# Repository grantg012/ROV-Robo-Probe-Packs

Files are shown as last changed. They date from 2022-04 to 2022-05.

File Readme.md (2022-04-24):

# Readme for ROV - Robo Probe Packs

This PCB serves as a integration layer for basic ROVs (though it could be
creatively used in other applications). It is designed for modularity and
fitting multiple different configurations. Perfect for high schoolers with
a little electronics experience, but not PCB design.

Features include:
* Pins for connecting to an Arduino Uno or Mega (use double sides ones for best effect)
* 12V+ input with reverse voltage protection
* Connections to common 12V -> 5V converters (such as ...)
* Up to 6 Electronic Speed Controllers (with options for protection circuitry)
* Breakouts for servos and I2C
* Primarily through hole components for easy soldering

## See `versions` for schematic PDFs and gerber files

## Parts List
* Arduino Uno or Mega
* Anderson power pole to PCB (1377G12 or similar)

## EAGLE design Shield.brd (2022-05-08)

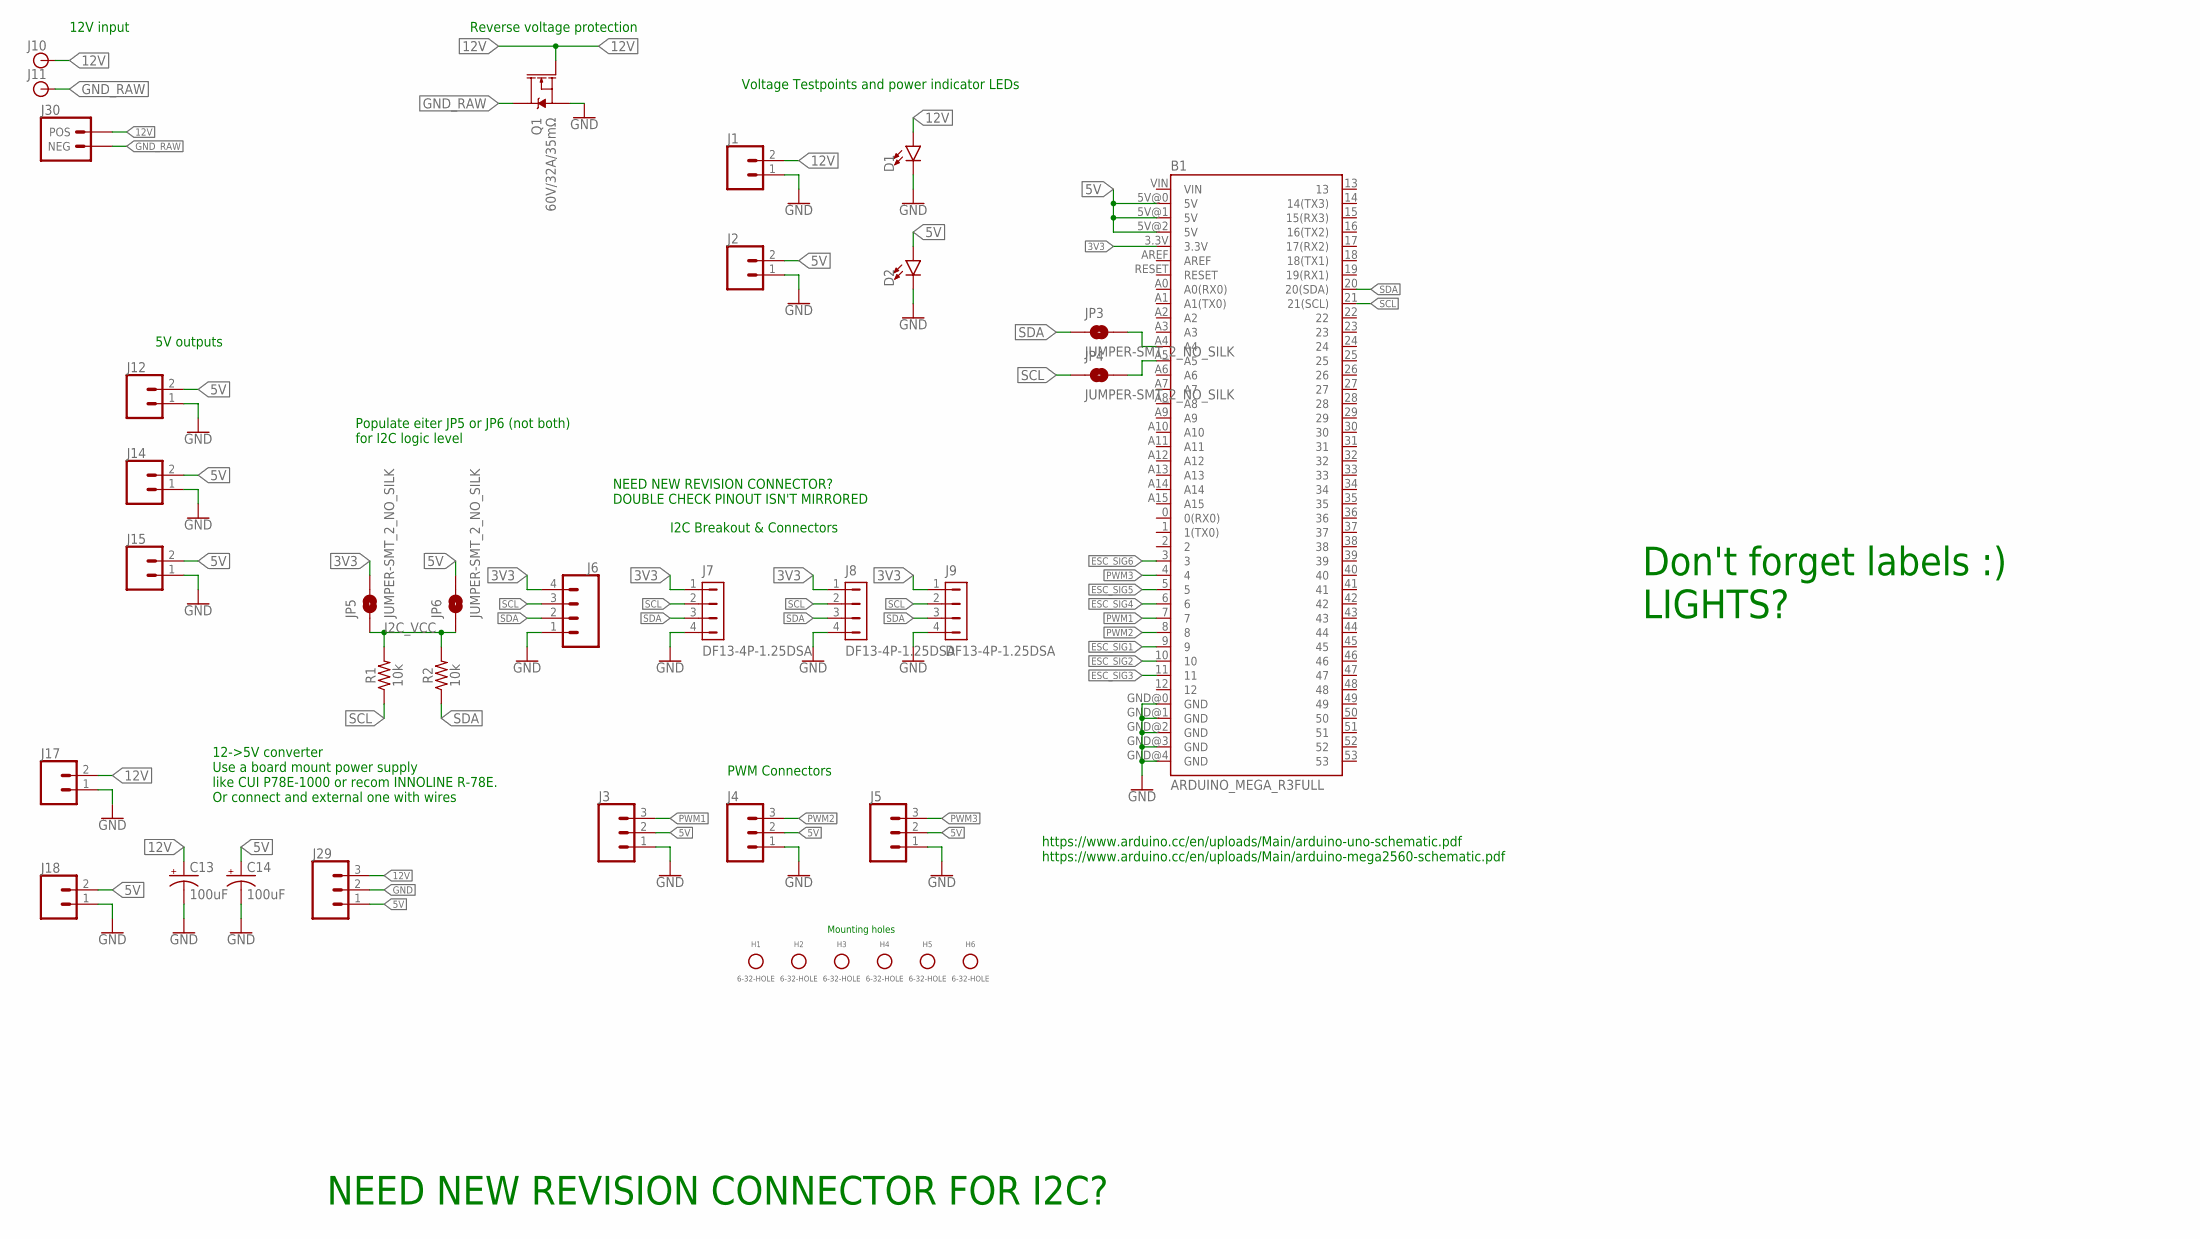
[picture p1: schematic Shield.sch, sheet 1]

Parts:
B1: ARDUINO_MEGA_R3FULL; ARDUINO_MEGA
C13, C14: 100uF; CPOL-RADIAL-2.5MM-6.5MM
D1, D2: LED3MM; LED_3MM
H1, H2, H3, H4, H5, H6: 6-32-HOLE
J1, J2, J12, J14, J15, J17, J18: CONN_02; 1X02
J3, J4, J5, J29: CONN_03; 1X03
J6: CONN_04; 1X04
J7, J8, J9: DF13-4P-1.25DSA
J10, J11: BANANA_PTH; BANANA_CONN_NO_THERM
J30: ANDERON_POWERPOLE_2
JP3, JP4, JP5, JP6: JUMPER-SMT_2_NO_SILK; SMT-JUMPER_2_NO_SILK
Q1: 60V/32A/35mΩ; TO220V
R1, R2: 10k; AXIAL-0.3

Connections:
3V3: B1.3.3V, J6.4, J7.1, J8.1, J9.1, JP5.2
5V: B1.5V@0 (5V), B1.5V@1 (5V), B1.5V@2 (5V), C14.1 (+), D2.A, J2.2, J3.2, J4.2, J5.2, J12.2, J14.2, J15.2, J18.2, J29.1, JP6.2
12V: C13.1 (+), D1.A, J1.2, J10.1, J17.2, J29.3, J30.POS, Q1.1 (G); also elsewhere on the board
A4_SDA: B1.A4, JP3.2
A5_SCL: B1.A5, JP4.2
ESC_SIG1: B1.9; also elsewhere on the board
ESC_SIG2: B1.10; also elsewhere on the board
ESC_SIG3: B1.11; also elsewhere on the board
ESC_SIG4: B1.6; also elsewhere on the board
ESC_SIG5: B1.5; also elsewhere on the board
ESC_SIG6: B1.3; also elsewhere on the board
GND: B1.GND@0 (GND), B1.GND@1 (GND), B1.GND@2 (GND), B1.GND@3 (GND), B1.GND@4 (GND), C13.2 (-), C14.2 (-), D1.K (C), D2.K (C), J1.1, J2.1, J3.1, J4.1, J5.1, J6.1, J7.4, J8.4, J9.4, J12.1, J14.1, J15.1, J17.1, J18.1, J29.2, Q1.3 (S); also elsewhere on the board
GND_RAW: J11.1, J30.NEG, Q1.2 (D)
I2C_VCC: JP5.1, JP6.1, R1.P$2 (2), R2.P$2 (2)
PWM1: B1.7, J3.3
PWM2: B1.8, J4.3
PWM3: B1.4, J5.3
SCL: B1.21 (21(SCL)), J6.3, J7.2, J8.2, J9.2, JP4.1, R1.P$1 (1)
SDA: B1.20 (20(SDA)), J6.2, J7.3, J8.3, J9.3, JP3.1, R2.P$1 (1)

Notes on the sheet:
12V input
12->5V converter Use a board mount power supply like CUI P78E-1000 or recom INNOLINE R-78E. Or connect and external one with wires
5V outputs
https://www.arduino.cc/en/uploads/Main/arduino-uno-schematic.pdf https://www.arduino.cc/en/uploads/Main/arduino-mega2560-schematic.pdf
Reverse voltage protection
Voltage Testpoints and power indicator LEDs
Don't forget labels :) LIGHTS?
I2C Breakout & Connectors
PWM Connectors
Mounting holes
Populate eiter JP5 or JP6 (not both) for I2C logic level
NEED NEW REVISION CONNECTOR? DOUBLE CHECK PINOUT ISN'T MIRRORED
NEED NEW REVISION CONNECTOR FOR I2C?

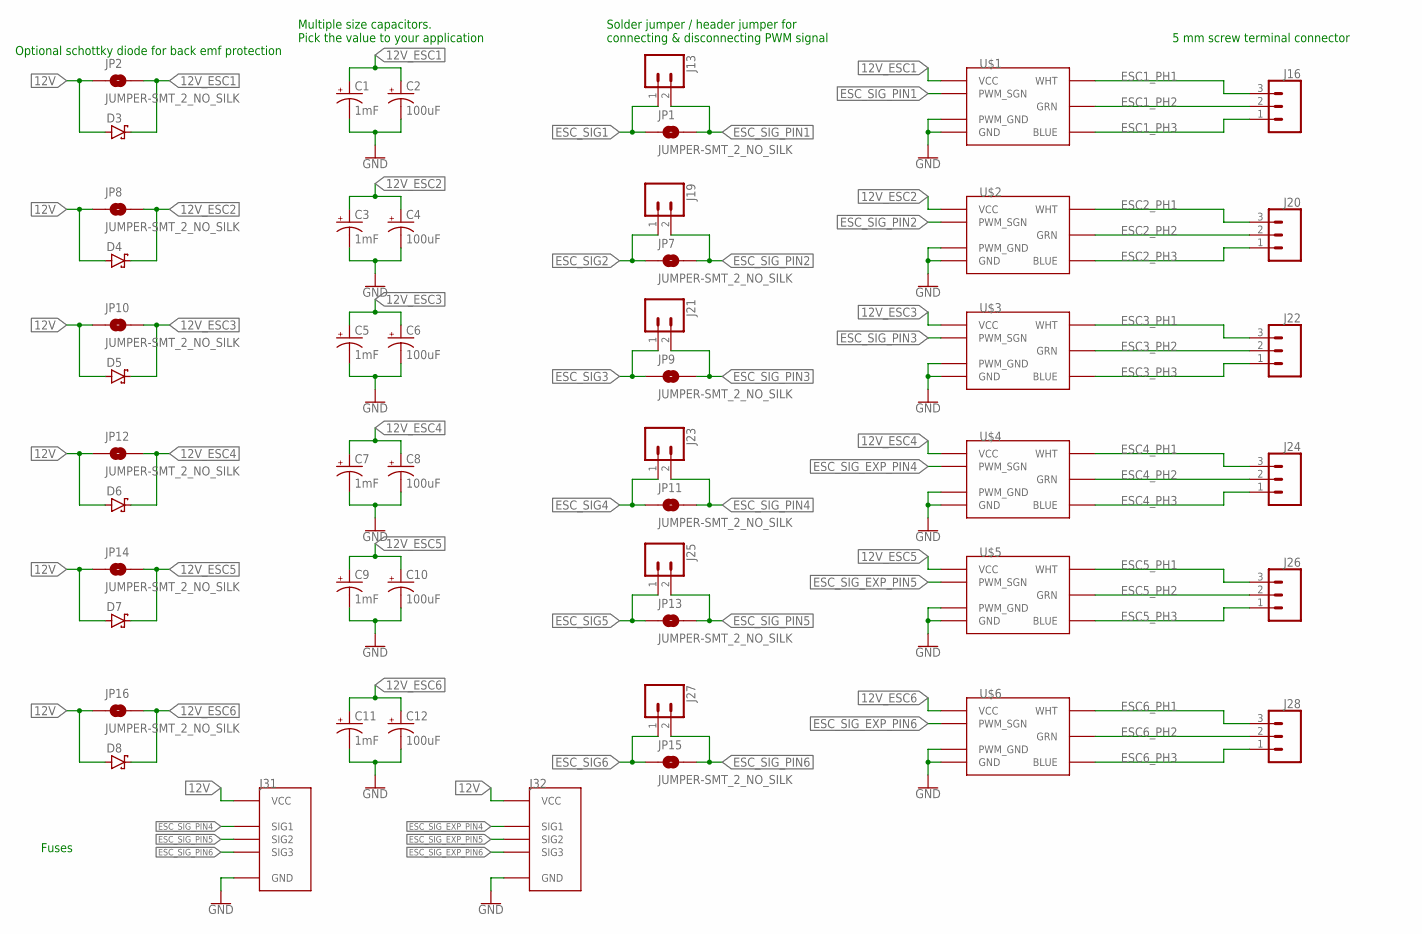
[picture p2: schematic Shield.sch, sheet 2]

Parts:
C1, C3, C5, C7, C9, C11: 1mF; CPOL-RADIAL-5MM-10MM
C2, C4, C6, C8, C10, C12: 100uF; CPOL-RADIAL-2.5MM-6.5MM
D3, D4, D5, D6, D7, D8: SCHOTTKY-DIODECB429-15; CB429-15
J13, J19, J21, J23, J25, J27: CONN_02; 1X02
J16, J20, J22, J24, J26, J28: CONN_03-SCREW-5MM; SCREWTERMINAL-5MM-3
J31, J32: ESC_EXPANSION_CONNECTOR; EXPANSION
JP1, JP2, JP7, JP8, JP9, JP10, JP11, JP12, JP13, JP14, JP15, JP16: JUMPER-SMT_2_NO_SILK; SMT-JUMPER_2_NO_SILK
U$1, U$2, U$3, U$4, U$5, U$6: ESC

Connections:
12V: D3.A, D4.A, D5.A, D6.A, D7.A, D8.A, J31.15 (VCC), J31.16 (VCC), J31.17 (VCC), J31.18 (VCC), J31.19 (VCC), J31.20 (VCC), J31.21 (VCC), J31.22 (VCC), J31.23 (VCC), J31.24 (VCC), J32.15 (VCC), J32.16 (VCC), J32.17 (VCC), J32.18 (VCC), J32.19 (VCC), J32.20 (VCC), J32.21 (VCC), J32.22 (VCC), J32.23 (VCC), J32.24 (VCC), JP2.1, JP8.1, JP10.1, JP12.1, JP14.1, JP16.1; also elsewhere on the board
12V_ESC1: C1.+, C2.1 (+), D3.C, JP2.2, U$1.VCC
12V_ESC2: C3.+, C4.1 (+), D4.C, JP8.2, U$2.VCC
12V_ESC3: C5.+, C6.1 (+), D5.C, JP10.2, U$3.VCC
12V_ESC4: C7.+, C8.1 (+), D6.C, JP12.2, U$4.VCC
12V_ESC5: C9.+, C10.1 (+), D7.C, JP14.2, U$5.VCC
12V_ESC6: C11.+, C12.1 (+), D8.C, JP16.2, U$6.VCC
ESC1_PH1: J16.3, U$1.BLUE (WHT)
ESC1_PH2: J16.2, U$1.GRN
ESC1_PH3: J16.1, U$1.WHT (BLUE)
ESC2_PH1: J20.3, U$2.BLUE (WHT)
ESC2_PH2: J20.2, U$2.GRN
ESC2_PH3: J20.1, U$2.WHT (BLUE)
ESC3_PH1: J22.3, U$3.BLUE (WHT)
ESC3_PH2: J22.2, U$3.GRN
ESC3_PH3: J22.1, U$3.WHT (BLUE)
ESC4_PH1: J24.3, U$4.BLUE (WHT)
ESC4_PH2: J24.2, U$4.GRN
ESC4_PH3: J24.1, U$4.WHT (BLUE)
ESC5_PH1: J26.3, U$5.BLUE (WHT)
ESC5_PH2: J26.2, U$5.GRN
ESC5_PH3: J26.1, U$5.WHT (BLUE)
ESC6_PH1: J28.3, U$6.BLUE (WHT)
ESC6_PH2: J28.2, U$6.GRN
ESC6_PH3: J28.1, U$6.WHT (BLUE)
ESC_SIG1: J13.1, JP1.1; also elsewhere on the board
ESC_SIG2: J19.1, JP7.1; also elsewhere on the board
ESC_SIG3: J21.1, JP9.1; also elsewhere on the board
ESC_SIG4: J23.1, JP11.1; also elsewhere on the board
ESC_SIG5: J25.1, JP13.1; also elsewhere on the board
ESC_SIG6: J27.1, JP15.1; also elsewhere on the board
ESC_SIG_EXP_PIN4: J32.11 (SIG1), U$4.PWM_SGN
ESC_SIG_EXP_PIN5: J32.12 (SIG2), U$5.PWM_SGN
ESC_SIG_EXP_PIN6: J32.13 (SIG3), U$6.PWM_SGN
ESC_SIG_PIN1: J13.2, JP1.2, U$1.PWM_SGN
ESC_SIG_PIN2: J19.2, JP7.2, U$2.PWM_SGN
ESC_SIG_PIN3: J21.2, JP9.2, U$3.PWM_SGN
ESC_SIG_PIN4: J23.2, J31.11 (SIG1), JP11.2
ESC_SIG_PIN5: J25.2, J31.12 (SIG2), JP13.2
ESC_SIG_PIN6: J27.2, J31.13 (SIG3), JP15.2
GND: C1.-, C2.2 (-), C3.-, C4.2 (-), C5.-, C6.2 (-), C7.-, C8.2 (-), C9.-, C10.2 (-), C11.-, C12.2 (-), J31.1 (GND), J31.2 (GND), J31.3 (GND), J31.4 (GND), J31.5 (GND), J31.6 (GND), J31.7 (GND), J31.8 (GND), J31.9 (GND), J31.10 (GND), J32.1 (GND), J32.2 (GND), J32.3 (GND), J32.4 (GND), J32.5 (GND), J32.6 (GND), J32.7 (GND), J32.8 (GND), J32.9 (GND), J32.10 (GND), U$1.GND, U$1.PWM_GND, U$2.GND, U$2.PWM_GND, U$3.GND, U$3.PWM_GND, U$4.GND, U$4.PWM_GND, U$5.GND, U$5.PWM_GND, U$6.GND, U$6.PWM_GND; also elsewhere on the board

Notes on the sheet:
Fuses
Solder jumper / header jumper for connecting & disconnecting PWM signal
Multiple size capacitors. Pick the value to your application
Optional schottky diode for back emf protection
5 mm screw terminal connector

Board: 2 copper layers, 86 parts (1 on the bottom side), 52 nets, no tracks yet.

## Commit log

2022-04-21 More to do listing
    [Shield.sch]
2022-04-23 Split into two sheets and add most existing parts
    [Shield.sch]
2022-04-24 Finish all parts except fuses
    [Shield.sch]
2022-04-24 Switch to GPL License
2022-04-30 Add caps around buck converter (fixes #1)
    [Shield.sch]
2022-05-08 Size ESC for 0.1" gnd & sig headers. Add and use expansion.
    [Shield.sch]
2022-05-08 Begin board placement
    [Shield.brd, Shield.sch]

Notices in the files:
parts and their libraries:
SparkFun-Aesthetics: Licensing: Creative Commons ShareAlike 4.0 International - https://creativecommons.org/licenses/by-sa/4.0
